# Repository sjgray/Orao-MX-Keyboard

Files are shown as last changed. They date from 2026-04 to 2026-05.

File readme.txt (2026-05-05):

Orao 2007 MX Keyboard - By Walter Miraglia and Steve Gray
=====================   Updated: 2026-05-05

This is a mechanical keyboard for the Orao 2007 computer.
It is based on the original keyboard but is slightly modified.

The changes are:

- Larger SHIFT keys.
- Larger ENTER key.
- Relocated cursor/arrow keys with Inverted-T configuration.
- Relocated and re-arranged PF keys.
- 6.25U SPACEBAR, 1.5U ENTER and SHIFT keys.

MX Switches
-----------

This design takes standard MX 3-pin or 5-pin cherry-type switches.
Five-pin switches are recommended for easier alignment.

Keycaps
-------

As this layout is unique I suggest you get blank DSA or XDA keycaps
and use sticker or waterslide sheets to label the keys. There are two
Keycap Sheets; One for Light keycaps (White, Grey,Beige etc) and one
for Black keycaps. The original keyboard was used as a guide and
additional alternate labels are included such as the PF key's actual
functions, longer names for some keys, and alternate cursor arrows.

For Light keycaps I suggest using Water-slide sheets (aka decal sheets).
For Black keycaps you can use full-page sticker sheets.

Connection
----------

For Rev 1 you will need a 16-pin ribbon cable to connect to the computer pcb.
The DIP connector matches the IC socket on the Orao PCB. Rev 2 and 2b can
also use an IDC or straight Dupont connector.

 The Dupont connector can be a 90 degree header installed on either the top
or bottom of the PCB. For Dupont cables you should use the square-pin male
headers on the Orao PCB. For the IDC connecter, I have seen pre-made
IDC to DIP ribbon cables on AliExpress.

History
-------

2026-04-10 - Rev 1 - Prototype. PCB's made. Needs fixes for function keys and SPACEBAR.
2026-04-30 - Rev 2 - Fix for Function key routing, SPACEBAR position, board size reduced. Add IDC and Dupont cable options.
2026-05-02 - Rev 2b- Revert to original size pcb. This revision is recommended for Walter's 3D case design.
2026-05-05 - Add Keycap Sheets

Steve

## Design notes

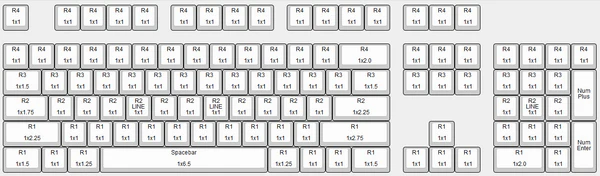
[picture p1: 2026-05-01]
Rev2/ANSI Layout.webp

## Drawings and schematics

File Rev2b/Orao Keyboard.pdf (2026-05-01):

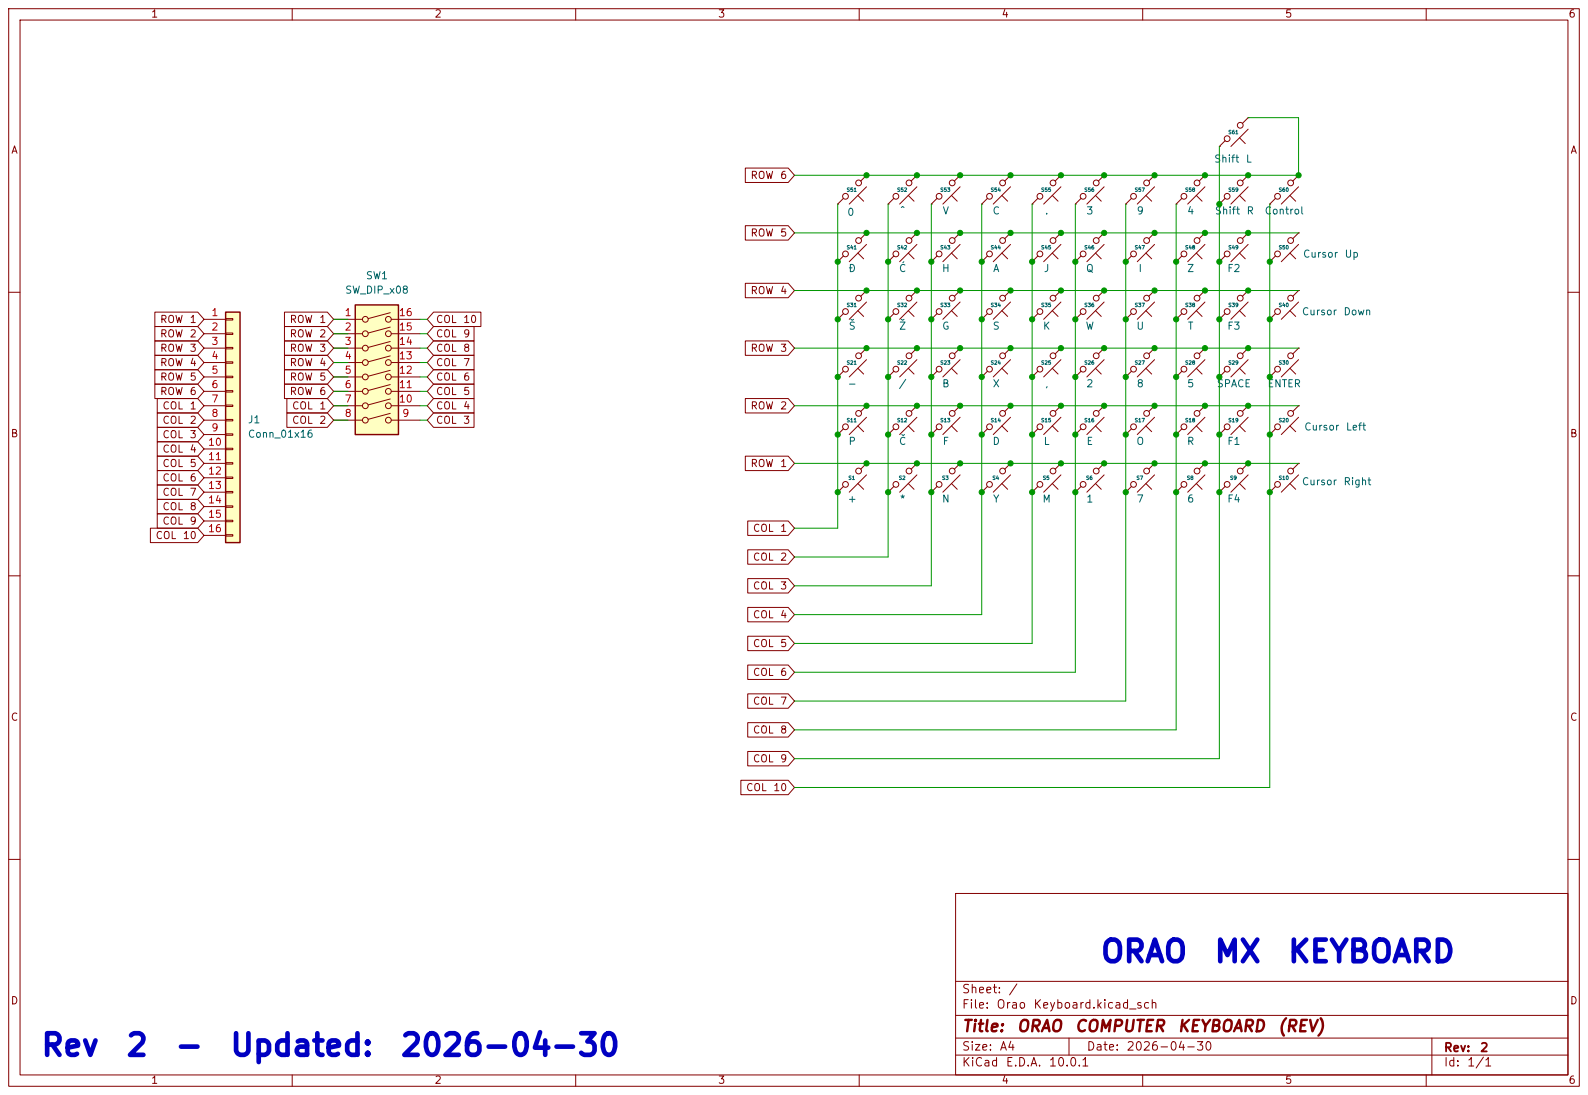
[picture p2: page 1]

Sheet: /
File: Orao Keyboard.kicad_sch
Title: ORAO COMPUTER KEYBOARD (REV)

Size: A4 | Rev: 2
KiCad E.D.A. 10.0.1 | Id: 1/1

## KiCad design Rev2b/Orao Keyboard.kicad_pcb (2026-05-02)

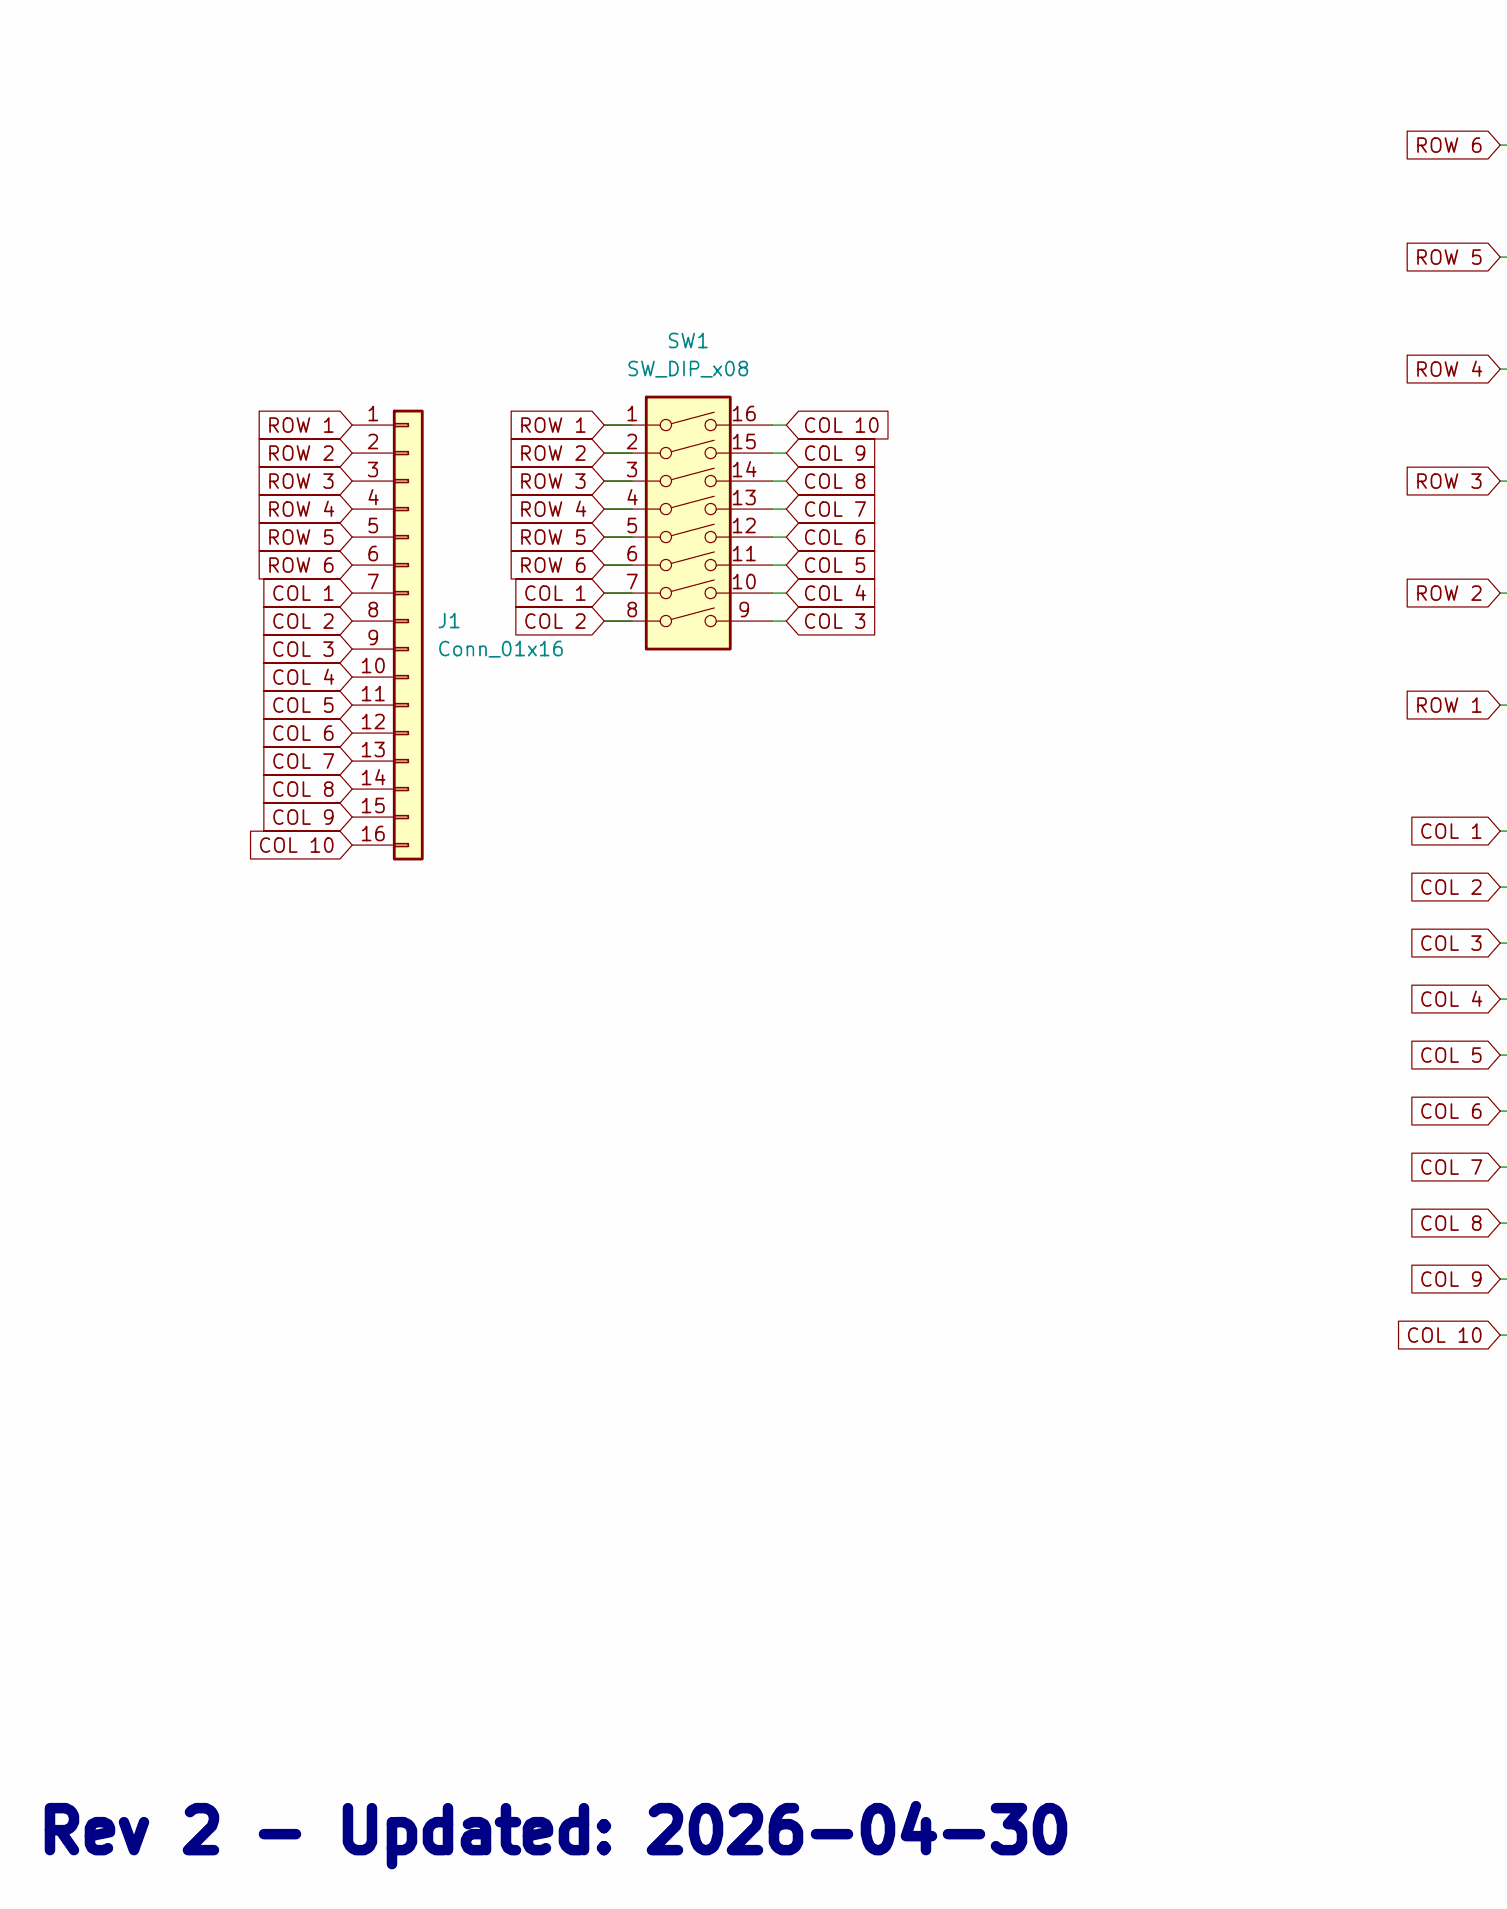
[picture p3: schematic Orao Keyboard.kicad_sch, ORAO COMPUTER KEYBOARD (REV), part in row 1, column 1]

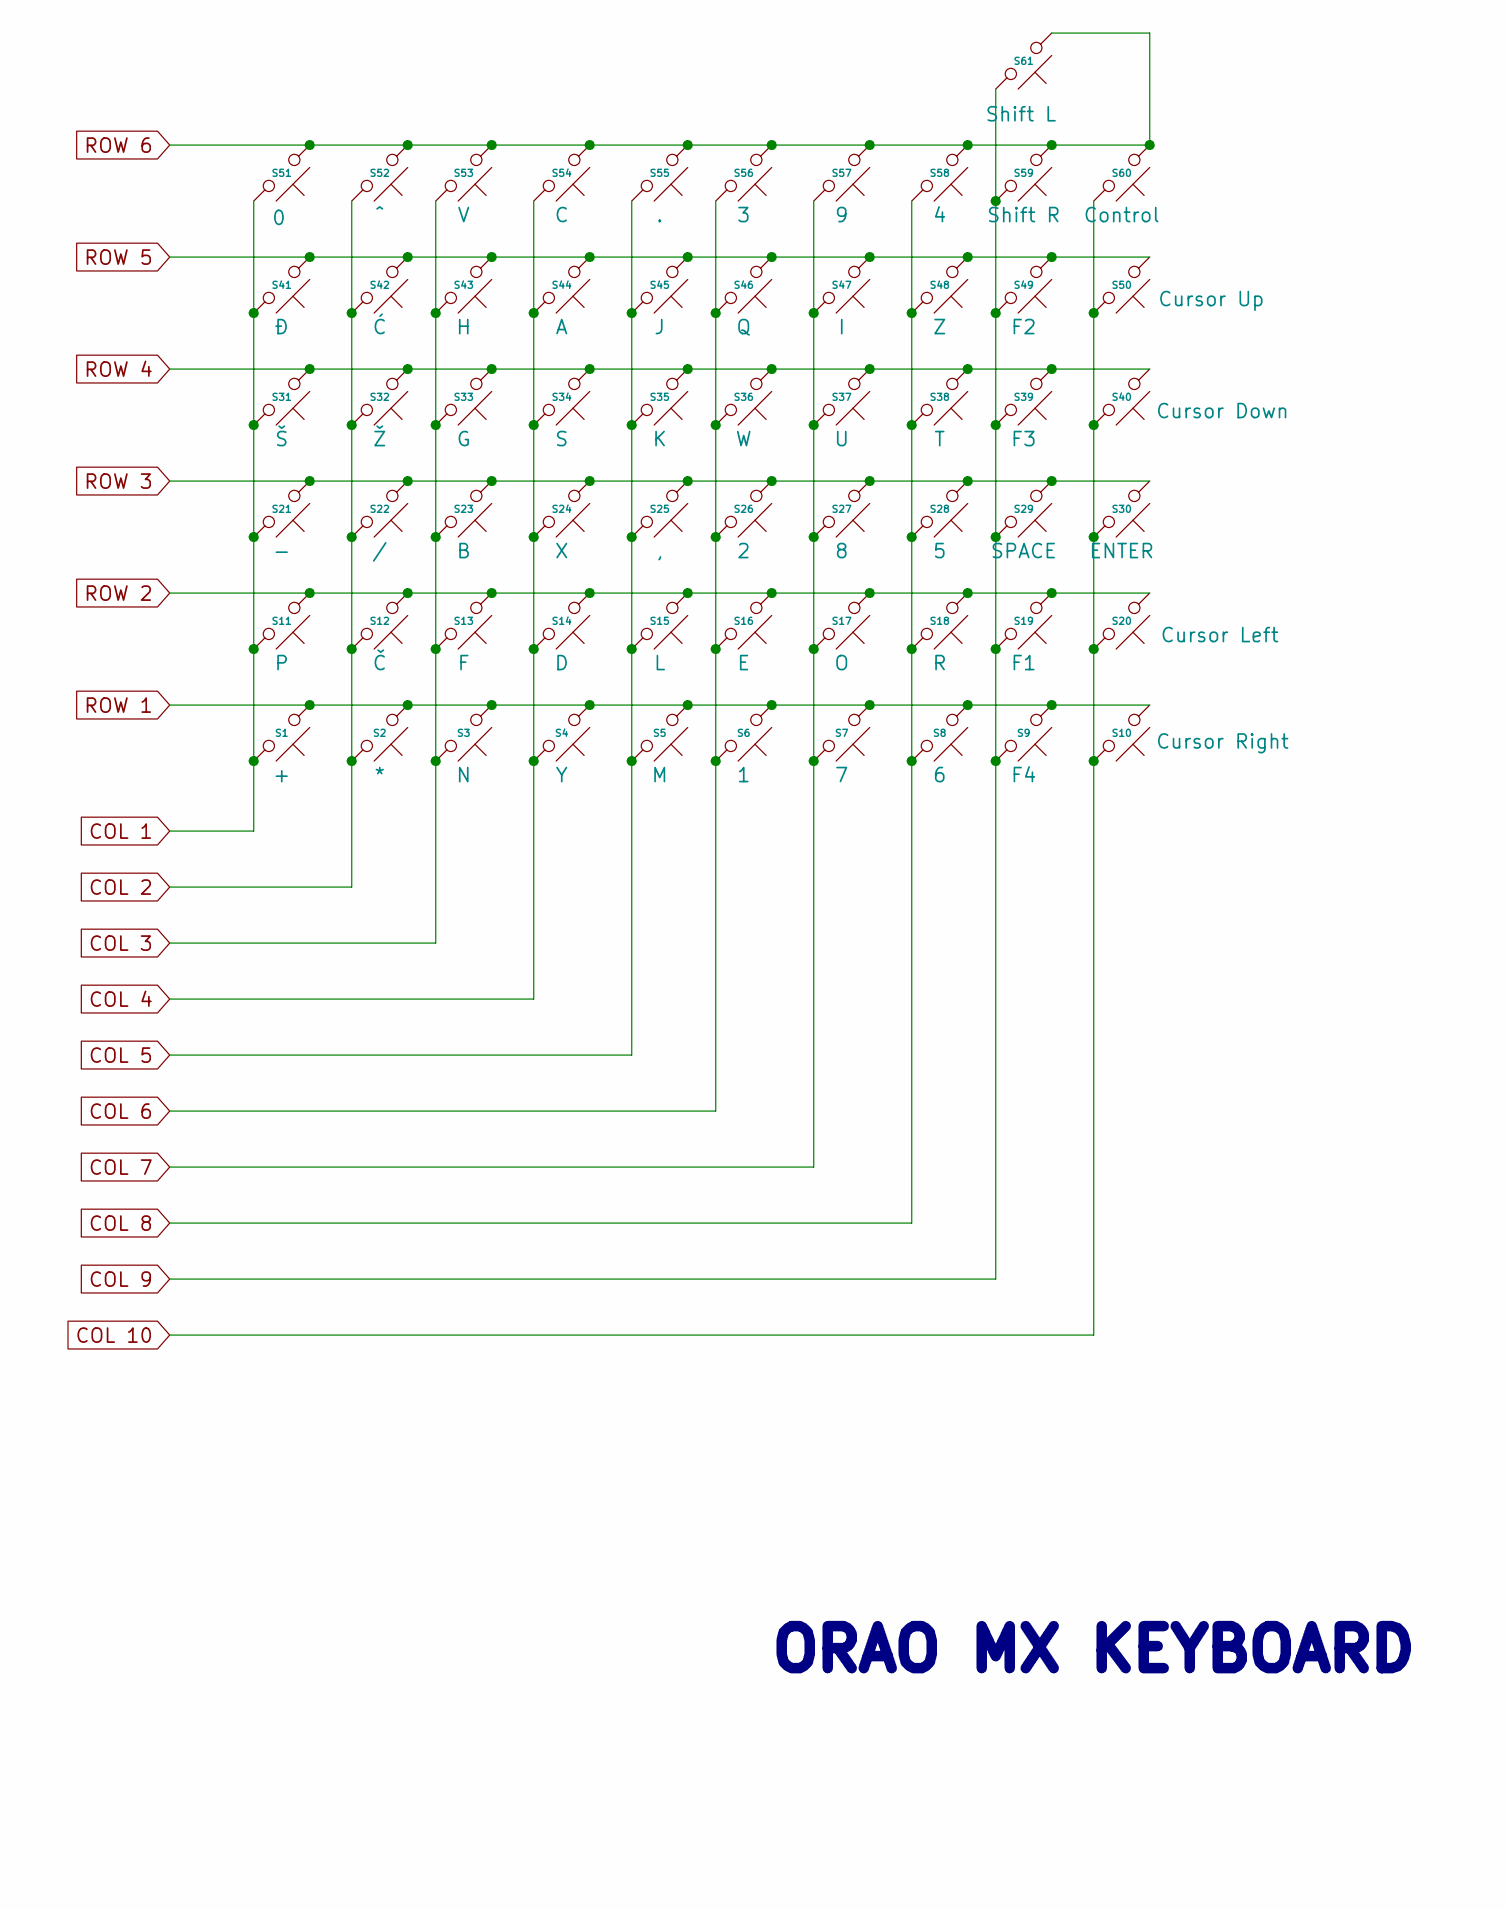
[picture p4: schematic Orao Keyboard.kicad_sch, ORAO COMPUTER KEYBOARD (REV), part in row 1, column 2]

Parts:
J1: Conn_01x16; PinHeader_1x16_P2.54mm_Vertical
S1: +; MX_PCB_1.00u
S2: *; MX_PCB_1.00u
S3: N; MX_PCB_1.00u
S4: Y; MX_PCB_1.00u
S5: M; MX_PCB_1.00u
S6: 1; MX_PCB_1.00u
S7: 7; MX_PCB_1.00u
S8: 6; MX_PCB_1.00u
S9: F4; MX_PCB_1.00u
S10: Cursor Right; MX_PCB_1.00u
S11: P; MX_PCB_1.00u
S12: Č; MX_PCB_1.00u
S13: F; MX_PCB_1.00u
S14: D; MX_PCB_1.00u
S15: L; MX_PCB_1.00u
S16: E; MX_PCB_1.00u
S17: O; MX_PCB_1.00u
S18: R; MX_PCB_1.00u
S19: F1; MX_PCB_1.00u
S20: Cursor Left; MX_PCB_1.00u
S21: -; MX_PCB_1.00u
S22: /; MX_PCB_1.00u
S23: B; MX_PCB_1.00u
S24: X; MX_PCB_1.00u
S25: ,; MX_PCB_1.00u
S26: 2; MX_PCB_1.00u
S27: 8; MX_PCB_1.00u
S28: 5; MX_PCB_1.00u
S29: SPACE; MX_PCB_6.25u
S30: ENTER; MX_PCB_1.50u
S31: Š; MX_PCB_1.00u
S32: Ž; MX_PCB_1.00u
S33: G; MX_PCB_1.00u
S34: S; MX_PCB_1.00u
S35: K; MX_PCB_1.00u
S36: W; MX_PCB_1.00u
S37: U; MX_PCB_1.00u
S38: T; MX_PCB_1.00u
S39: F3; MX_PCB_1.00u
S40: Cursor Down; MX_PCB_1.00u
S41: Đ; MX_PCB_1.00u
S42: Ć; MX_PCB_1.00u
S43: H; MX_PCB_1.00u
S44: A; MX_PCB_1.00u
S45: J; MX_PCB_1.00u
S46: Q; MX_PCB_1.00u
S47: I; MX_PCB_1.00u
S48: Z; MX_PCB_1.00u
S49: F2; MX_PCB_1.00u
S50: Cursor Up; MX_PCB_1.00u
S51: 0; MX_PCB_1.00u
S52: ^; MX_PCB_1.00u
S53: V; MX_PCB_1.00u
S54: C; MX_PCB_1.00u
S55: .; MX_PCB_1.00u
S56: 3; MX_PCB_1.00u
S57: 9; MX_PCB_1.00u
S58: 4; MX_PCB_1.00u
S59: Shift R; MX_PCB_1.50u
S60: Control; MX_PCB_1.00u
S61: Shift L; MX_PCB_1.50u
SW1: SW_DIP_x08; CERDIP-16_W7.62mm_SideBrazed_LongPads

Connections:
COL 1: J1.7, S1.1, S11.1, S21.1, S31.1, S41.1, S51.1, SW1.7
COL 2: J1.8, S2.1, S12.1, S22.1, S32.1, S42.1, S52.1, SW1.8
COL 3: J1.9, S3.1, S13.1, S23.1, S33.1, S43.1, S53.1, SW1.9
COL 4: J1.10, S4.1, S14.1, S24.1, S34.1, S44.1, S54.1, SW1.10
COL 5: J1.11, S5.1, S15.1, S25.1, S35.1, S45.1, S55.1, SW1.11
COL 6: J1.12, S6.1, S16.1, S26.1, S36.1, S46.1, S56.1, SW1.12
COL 7: J1.13, S7.1, S17.1, S27.1, S37.1, S47.1, S57.1, SW1.13
COL 8: J1.14, S8.1, S18.1, S28.1, S38.1, S48.1, S58.1, SW1.14
COL 9: J1.15, S9.1, S19.1, S29.1, S39.1, S49.1, S59.1, S61.1, SW1.15
COL 10: J1.16, S10.1, S20.1, S30.1, S40.1, S50.1, S60.1, SW1.16
ROW 1: J1.1, S1.2, S2.2, S3.2, S4.2, S5.2, S6.2, S7.2, S8.2, S9.2, S10.2, SW1.1
ROW 2: J1.2, S11.2, S12.2, S13.2, S14.2, S15.2, S16.2, S17.2, S18.2, S19.2, S20.2, SW1.2
ROW 3: J1.3, S21.2, S22.2, S23.2, S24.2, S25.2, S26.2, S27.2, S28.2, S29.2, S30.2, SW1.3
ROW 4: J1.4, S31.2, S32.2, S33.2, S34.2, S35.2, S36.2, S37.2, S38.2, S39.2, S40.2, SW1.4
ROW 5: J1.5, S41.2, S42.2, S43.2, S44.2, S45.2, S46.2, S47.2, S48.2, S49.2, S50.2, SW1.5
ROW 6: J1.6, S51.2, S52.2, S53.2, S54.2, S55.2, S56.2, S57.2, S58.2, S59.2, S60.2, S61.2, SW1.6

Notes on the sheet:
ORAO MX KEYBOARD
Rev 2 - Updated: 2026-04-30

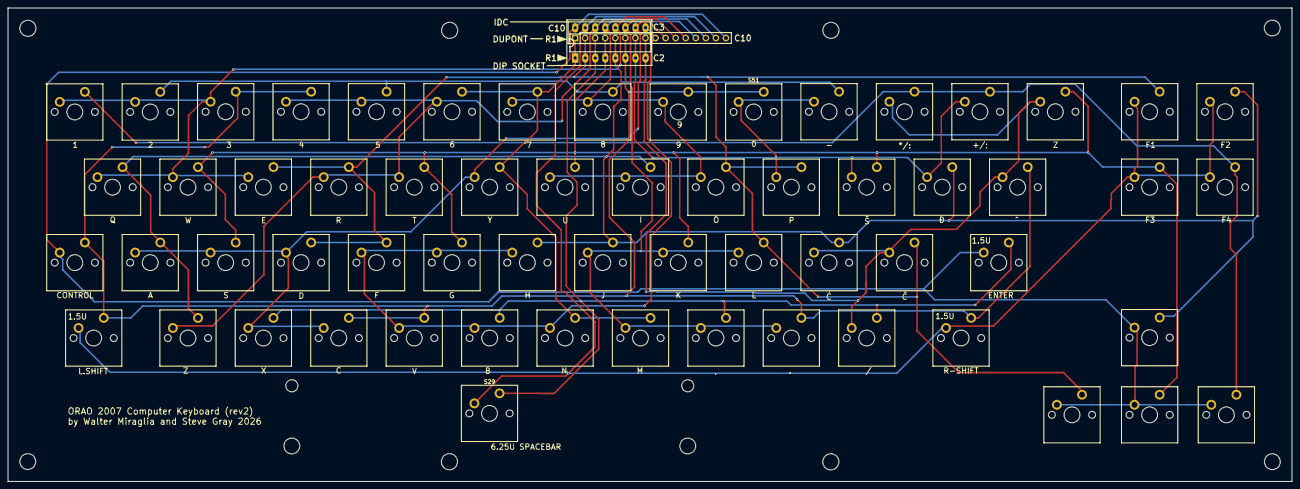
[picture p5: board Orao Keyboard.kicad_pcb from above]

Board: 2 copper layers, 324.3 x 119.6 mm, 63 parts (0 on the bottom side), 16 nets.

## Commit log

2026-04-12 Initial design
    Initial design. Untested. Please wait until confirmed working before ordering boards!
    [Orao Keyboard-B_Cu.gbr, Orao Keyboard-B_Mask.gbr, Orao Keyboard-B_Paste.gbr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]
2026-05-01 Rev 2
    Same layout as Rev 1. Fixes for function keys and SPACEBAR position. Add additional ribbon cable options - IDC and Dupont. Dupont could be a 90 degree connector and mounted on the top or bottom of the board. Slightly smaller pcb.
    [Orao Keyboard-B_Cu.gbr, Orao Keyboard-B_Mask.gbr, Orao Keyboard-B_Paste.gbr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]
2026-05-02 Rev 2b
    Reverted to original PCB size.
    [Orao Keyboard-B_Cu.gbr, Orao Keyboard-B_Mask.gbr, Orao Keyboard-B_Paste.gbr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]
2026-05-02 Add additional connector info
    Add IDC and Dupont connector info.
